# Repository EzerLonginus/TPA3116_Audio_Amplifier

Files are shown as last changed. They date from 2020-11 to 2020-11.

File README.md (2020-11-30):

# TPA3116_Audio_Amplifier
TPA3116 Stereo and Sub-Woofer Audio Amplifier.  D-Class 50W Stereo Amplifier.  The schematic and layout are pretty much similar to the one layout in the datasheet.  Nothing too fancy, however the Subwoofer does have a summed Left and Right channel via two 470 ohm resistors `R78 R79`. The input is assumed to be a line level stereo input through a 3.5mm jack.  However, there are some through hole pins should a different connector or input be desired.  The banana plug holes on the all the speaker ouputs are for potential convenience for swapping out speakers.  Not strictly necessary, one could solder speaker cable to those through holes, or just juse the screw terminals.  The banana plugs for the power input are there for similar reasons.  

## Schematic
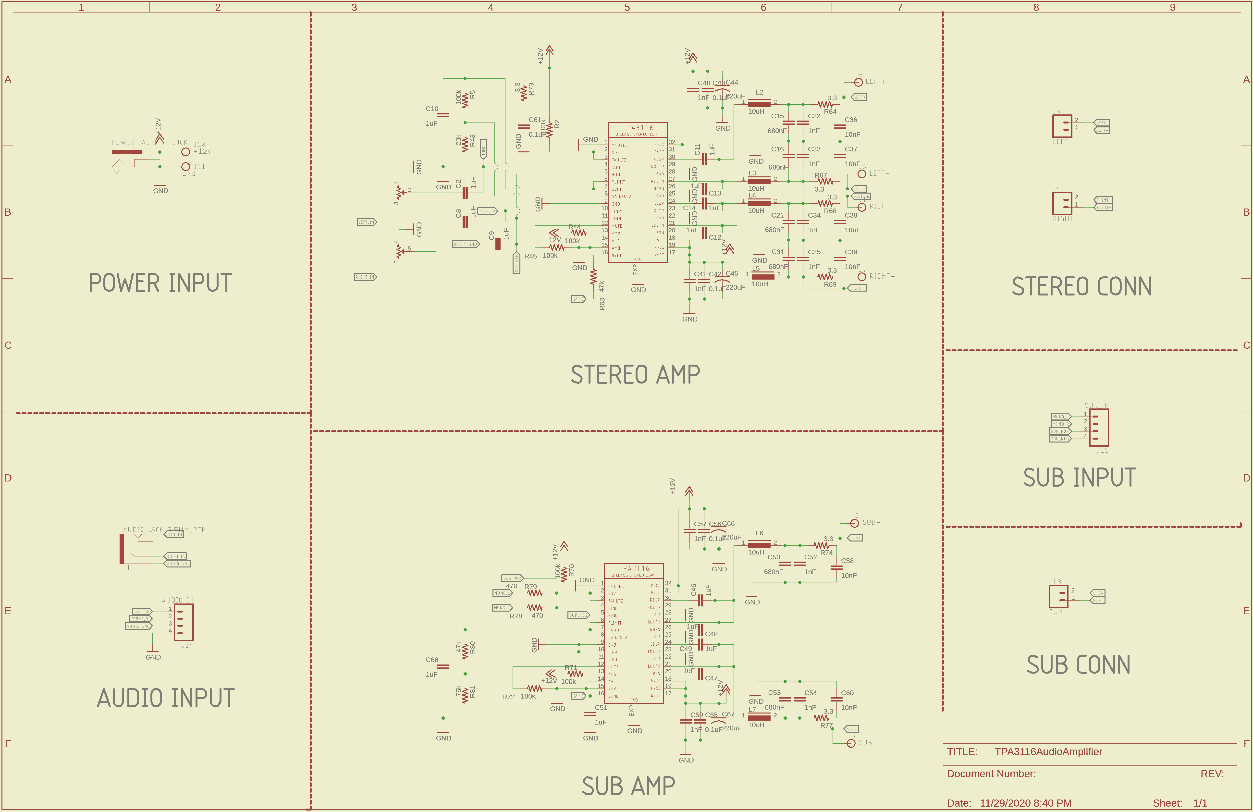
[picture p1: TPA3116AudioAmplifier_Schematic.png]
Schematic


## Layout
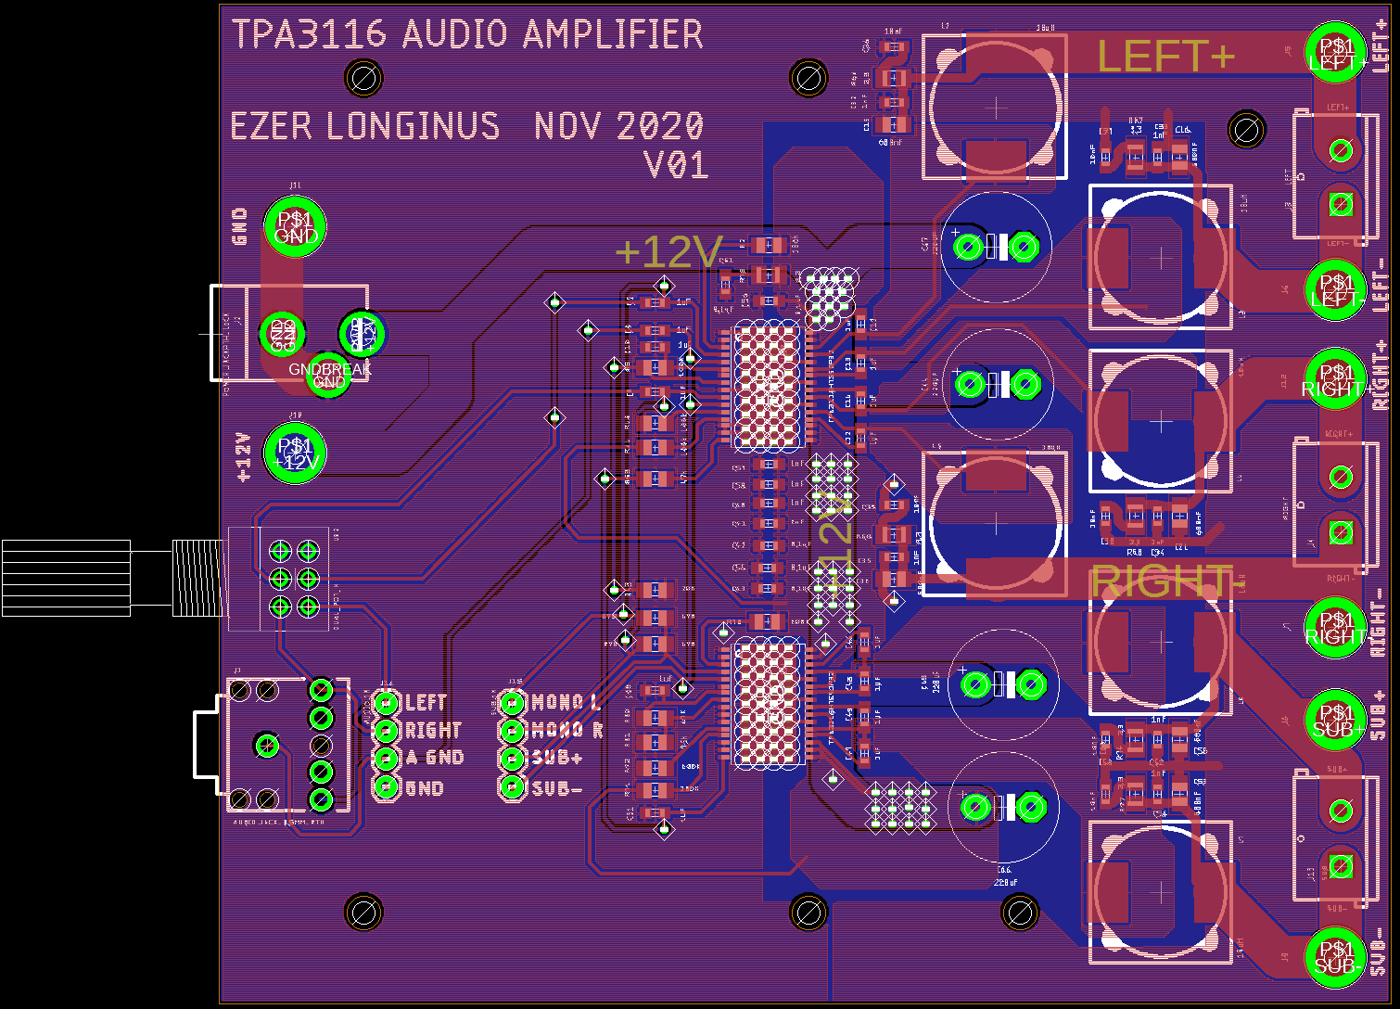
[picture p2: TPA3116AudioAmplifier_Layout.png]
Layout


## BOM Link
1. [OCTOPART BOM](https://octopart.com/bom-tool/Kn64f8nE)

## Datasheets and External Links
1. [TPA3116](https://www.ti.com/lit/ds/symlink/tpa3116d2.pdf)

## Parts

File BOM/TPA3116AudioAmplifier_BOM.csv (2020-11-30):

Qty | Line Item | Manufacturer | MPN | Octopart URL | Schematic Reference | Internal Part Number | Description | Total Qty (@ Batch Size: 1) | SKU | SKU | SKU | SKU | Packaging | Packaging | Packaging | Packaging | Unit Price (@ Batch Size: 1) | Unit Price (@ Batch Size: 1) | Unit Price (@ Batch Size: 1) | Unit Price (@ Batch Size: 1) | In Stock | In Stock | In Stock | In Stock | MOQ | MOQ | MOQ | MOQ | URL | URL | URL | URL | Distributor [Lowest Price (Overall)] | SKU [Lowest Price (Overall)] | Packaging [Lowest Price (Overall)] | Unit Price (@ Batch Size: 1) [Lowest Price (Overall)] | Line Total [Lowest Price (Overall)] | Batch Total [Lowest Price (Overall)] | In Stock [Lowest Price (Overall)] | MOQ [Lowest Price (Overall)] | URL [Lowest Price (Overall)] | Notes
 |  |  |  |  |  |  |  |  | Digi-Key | Future Electronics | Mouser | RS Components | Digi-Key | Future Electronics | Mouser | RS Components | Digi-Key | Future Electronics | Mouser | RS Components | Digi-Key | Future Electronics | Mouser | RS Components | Digi-Key | Future Electronics | Mouser | RS Components | Digi-Key | Future Electronics | Mouser | RS Components
14 | UMK107BJ105KA-T | Taiyo Yuden | UMK107BJ105KA-T | https://octopart.com/umk107bj105ka-t-taiyo+yuden-12090744 | C2 C8 C9 C10 C11 C12 C13 C14 C46 C47 C48 C49 C51 C68 |  | CAP CER 1UF 50V X5R 0603 | 14 | 587-2400-1-ND | 5104254 |  | 1034112 | Cut Tape | Cut Tape |  |  | 0.124 | 0.176 |  |  | 2043939 | 119583 |  | 4400 | 1 | 1 |  | 100 | https://octopart.com/click/track?ai=8237&sig=0510af6&sid=459&ppid=12090744&vpid=34090480&ct=offers | https://octopart.com/click/track?ai=8237&sig=0335285&sid=2454&ppid=12090744&vpid=495873363&ct=offers |  | https://octopart.com/click/track?ai=8237&sig=0923c07&sid=10022&ppid=12090744&vpid=575871653&ct=offers | Freelance Electronics | UMK107BJ105KA-T |  | 0.0096 | 0.1344 | 0.1344 | 1484 | 1 | https://octopart.com/click/track?ai=8237&sig=025401f&sid=13062&ppid=12090744&vpid=592344908&ct=offers
6 | CL21B684KBFVPNE | Samsung | CL21B684KBFVPNE | https://octopart.com/cl21b684kbfvpne-samsung-76986280 | C15 C16 C21 C31 C50 C53 |  | CAP CER 0.68UF 50V X7R 0805 | 6 | 1276-7009-1-ND |  |  |  | Cut Tape |  |  |  | 0.19 |  |  |  | 45805 |  |  |  | 1 |  |  |  | https://octopart.com/click/track?c=1&ai=8237&sig=0b574c6&sid=459&ppid=76986280&vpid=426278556&ct=offers |  |  |  | Digi-Key | 1276-7009-1-ND | Cut Tape | 0.19 | 1.1400000000000001 | 1.1400000000000001 | 45805 | 1 | https://octopart.com/click/track?c=1&ai=8237&sig=0b574c6&sid=459&ppid=76986280&vpid=426278556&ct=offers
9 | CL10B102KB8NNNC | Samsung | CL10B102KB8NNNC | https://octopart.com/cl10b102kb8nnnc-samsung-9301522 | C32 C33 C34 C40 C41 C52 C54 C57 C59 |  | CAP CER 1000PF 50V X7R 0603 | 9 | 1276-1018-1-ND | 3573581 |  | 7665272 | Cut Tape | Cut Tape |  |  | 0.1 | 0.0091 |  |  | 572722 | 1136132 |  | 136000 | 1 | 1 |  | 4000 | https://octopart.com/click/track?ai=8237&sig=0138e6a&sid=459&ppid=9301522&vpid=72523792&ct=offers | https://octopart.com/click/track?ai=8237&sig=0fb88a5&sid=2454&ppid=9301522&vpid=657046416&ct=offers |  | https://octopart.com/click/track?ai=8237&sig=094158c&sid=10022&ppid=9301522&vpid=575772081&ct=offers | Future Electronics | 3573581 | Cut Tape | 0.0091 | 0.0819 | 0.0819 | 1136132 | 1 | https://octopart.com/click/track?ai=8237&sig=0fb88a5&sid=2454&ppid=9301522&vpid=657046416&ct=offers
6 | CL10B103KB8NNNC | Samsung | CL10B103KB8NNNC | https://octopart.com/cl10b103kb8nnnc-samsung-9299374 | C36 C37 C38 C39 C58 C60 |  | CAP CER 10000PF 50V X7R 0603 | 6 | 1276-1009-1-ND | 7103639 |  | 7665373 | Cut Tape | Cut Tape |  |  | 0.1 | 0.0079 |  |  | 2658585 | 1432961 |  | 6232000 | 1 | 1 |  | 4000 | https://octopart.com/click/track?ai=8237&sig=08f0957&sid=459&ppid=9299374&vpid=72523832&ct=offers | https://octopart.com/click/track?ai=8237&sig=08b147c&sid=2454&ppid=9299374&vpid=495872440&ct=offers |  | https://octopart.com/click/track?ai=8237&sig=09d8818&sid=10022&ppid=9299374&vpid=575772086&ct=offers | Newark | 82AC9315 | Cut Tape | 0.005 | 0.03 | 0.03 | 44883 | 1 | https://octopart.com/click/track?ai=8237&sig=00bc199&sid=2402&ppid=9299374&vpid=511545493&ct=offers
5 | CL10B104KB8NNNL | Samsung | CL10B104KB8NNNL | https://octopart.com/cl10b104kb8nnnl-samsung-21395620 | C42 C43 C55 C56 C61 |  | CAP CER 0.1UF 50V X7R 0603 | 5 | 1276-CL10B104KB8NNNLCT-ND | 3113240 | 187-CL10B104KB8NNNL |  | Cut Tape | Cut Tape | Tape & Reel |  | 0.1 | 0.098 |  |  | 5868552 | 570651 | 438200 |  | 1 | 1 | 15000 |  | https://octopart.com/click/track?ai=8237&sig=0e9765d&sid=459&ppid=21395620&vpid=578720948&ct=offers | https://octopart.com/click/track?ai=8237&sig=0f2016f&sid=2454&ppid=21395620&vpid=657046465&ct=offers | https://octopart.com/click/track?ai=8237&sig=00540b2&sid=2401&ppid=21395620&vpid=659501131&ct=offers |  | Arrow.cn | CL10B104KB8NNNL#SAMSUNGE |  | 0.028 | 0.14 | 0.14 | 10928 | 1 | https://octopart.com/click/track?ai=8237&sig=07a3a2f&sid=28928&ppid=21395620&vpid=642249454&ct=offers
4 | ESE227M050AH9EA | KEMET | ESE227M050AH9EA | https://octopart.com/ese227m050ah9ea-kemet-92837938 | C44 C45 C66 C67 |  | CAP ALUM 220UF 20% 50V THRUHOLE | 4 | 399-18266-1-ND |  |  |  | Cut Tape |  |  |  | 0.37 |  |  |  | 101 |  |  |  | 1 |  |  |  | https://octopart.com/click/track?c=1&ai=8237&sig=0bcd6f5&sid=459&ppid=92837938&vpid=484652430&ct=offers |  |  |  | Digi-Key | 399-18266-1-ND | Cut Tape | 0.37 | 1.48 | 1.48 | 101 | 1 | https://octopart.com/click/track?c=1&ai=8237&sig=0bcd6f5&sid=459&ppid=92837938&vpid=484652430&ct=offers
1 | SJ1-3555NG | CUI Devices | SJ1-3555NG | https://octopart.com/sj1-3555ng-cui+devices-106234295 | J1 |  | CONN JACK STEREO 3.5MM R/A | 1 | CP1-3555NG-ND | 6034303 |  |  | Bag | Box |  |  | 0.9 | 0.55 |  |  | 14884 | 12500 |  |  | 1 | 1 |  |  | https://octopart.com/click/track?ai=8237&sig=028bb4d&sid=459&ppid=106234295&vpid=612420483&ct=offers | https://octopart.com/click/track?ai=8237&sig=02bc3c9&sid=2454&ppid=106234295&vpid=656992232&ct=offers |  |  | Future Electronics | 6034303 | Box | 0.55 | 0.55 | 0.55 | 12500 | 1 | https://octopart.com/click/track?ai=8237&sig=02bc3c9&sid=2454&ppid=106234295&vpid=656992232&ct=offers
3 | 282836-2 | TE Connectivity | 282836-2 | https://octopart.com/282836-2-te+connectivity-39396934 | J3 J4 J13 |  | TERM BLK 2POS SIDE ENTRY 5MM PCB | 3 | A98076-ND | 4188728 |  | 3617667 | Box | Bag |  |  | 0.71 | 0.295 |  |  | 34141 | 8601 |  | 5005 | 1 | 1 |  | 5 | https://octopart.com/click/track?ai=8237&sig=03766e2&sid=459&ppid=39396934&vpid=198635742&ct=offers | https://octopart.com/click/track?ai=8237&sig=0dfe638&sid=2454&ppid=39396934&vpid=416937788&ct=offers |  | https://octopart.com/click/track?ai=8237&sig=01d4f22&sid=10022&ppid=39396934&vpid=575813511&ct=offers | Sager Electronics | 282836-2 |  | 0.2355 | 0.7064999999999999 | 0.7064999999999999 | 0 | 1 | https://octopart.com/click/track?c=1&ai=8237&sig=0304f12&sid=15568&ppid=39396934&vpid=115559715&ct=offers
8 | 476-4 | Keystone | 476-4 | https://octopart.com/476-4-keystone-225161 | J5 J6 J7 J8 J9 J10 J11 J12 |  | CONN BANANA JACK MINIATURE SLDR | 8 | 36-476-4-ND |  | 534-476-4 |  | Bulk |  | Bulk |  | 0.69 |  | 0.66 |  | 3510 |  | 289 |  | 1 |  | 1 |  | https://octopart.com/click/track?ai=8237&sig=076c679&sid=459&ppid=225161&vpid=212427319&ct=offers |  | https://octopart.com/click/track?ai=8237&sig=075d1a8&sid=2401&ppid=225161&vpid=37932047&ct=offers |  | Carlton-Bates | 78382499741 |  | 0.64 | 5.12 | 5.12 | 0 | 1 | https://octopart.com/click/track?c=1&ai=8237&sig=0dcadd2&sid=18369&ppid=225161&vpid=521658433&ct=offers
6 | SRR1208-100ML | Bourns | SRR1208-100ML | https://octopart.com/srr1208-100ml-bourns-148118 | L2 L3 L4 L5 L6 L7 |  | FIXED IND 10UH 5A 21 MOHM SMD | 6 | SRR1208-100MLCT-ND |  |  | 6934530 | Cut Tape |  |  |  | 0.98 |  |  | 0.845 | 11953 |  |  | 221 | 1 |  |  | 1 | https://octopart.com/click/track?ai=8237&sig=01733f2&sid=459&ppid=148118&vpid=34264358&ct=offers |  |  | https://octopart.com/click/track?ai=8237&sig=0c0d7fa&sid=10022&ppid=148118&vpid=575456154&ct=offers | Avnet | 83R8946 |  | 0.47 | 2.82 | 2.82 | 800 | 1 | https://octopart.com/click/track?ai=8237&sig=0ac58d9&sid=5822&ppid=148118&vpid=503036623&ct=offers
7 | RR1220P-104-D | Susumu | RR1220P-104-D | https://octopart.com/rr1220p-104-d-susumu-981652 | R2 R5 R44 R46 R70 R71 R72 |  | RES SMD 100K OHM 0.5% 1/10W 0805 | 7 | RR12P100KDCT-ND | 2474021 |  | 3915719 | Cut Tape | Cut Tape |  |  | 0.1 | 0.108 |  |  | 368982 | 70469 |  | 500 | 1 | 1 |  | 100 | https://octopart.com/click/track?ai=8237&sig=0299d6a&sid=459&ppid=981652&vpid=1542037&ct=offers | https://octopart.com/click/track?ai=8237&sig=022a240&sid=2454&ppid=981652&vpid=19675409&ct=offers |  | https://octopart.com/click/track?ai=8237&sig=0dd98c3&sid=10022&ppid=981652&vpid=576840281&ct=offers | Newark | 28K0934 | Cut Tape | 0.013 | 0.091 | 0.091 | 26418 | 1 | https://octopart.com/click/track?ai=8237&sig=0f3df14&sid=2402&ppid=981652&vpid=2942947&ct=offers
1 | ERA-6AEB203V | Panasonic | ERA6AEB203V | https://octopart.com/era6aeb203v-panasonic-55396948 | R43 |  | RES 20K OHM 0.1% 1/8W 0805 | 1 | P20KDACT-ND | 5098752 |  |  | Cut Tape | Cut Tape |  |  | 0.31 | 0.355 |  |  | 50759 | 25110 |  |  | 1 | 1 |  |  | https://octopart.com/click/track?ai=8237&sig=0c06205&sid=459&ppid=55396948&vpid=118268838&ct=offers | https://octopart.com/click/track?ai=8237&sig=03b0c2d&sid=2454&ppid=55396948&vpid=477169642&ct=offers |  |  | Avnet | 01X1369 |  | 0.044 | 0.044 | 0.044 | 35000 | 1 | https://octopart.com/click/track?ai=8237&sig=03a8e8a&sid=5822&ppid=55396948&vpid=503227276&ct=offers
2 | RC0805FR-0747KL | Yageo | RC0805FR-0747KL | https://octopart.com/rc0805fr-0747kl-yageo-41205014 | R63 R80 |  | RES SMD 47K OHM 1% 1/8W 0805 | 2 | 311-47.0KCRCT-ND | 2963700 |  | 6182580 | Cut Tape | Cut Tape |  |  | 0.1 | 0.0041 |  |  | 903107 | 1316495 |  | 50000 | 1 | 1 |  | 5000 | https://octopart.com/click/track?ai=8237&sig=0fa6774&sid=459&ppid=41205014&vpid=114983320&ct=offers | https://octopart.com/click/track?ai=8237&sig=01c416f&sid=2454&ppid=41205014&vpid=416982216&ct=offers |  | https://octopart.com/click/track?ai=8237&sig=0af9f31&sid=10022&ppid=41205014&vpid=575956811&ct=offers | Future Electronics | 2963700 | Cut Tape | 0.0041 | 0.0082 | 0.0082 | 1316495 | 1 | https://octopart.com/click/track?ai=8237&sig=01c416f&sid=2454&ppid=41205014&vpid=416982216&ct=offers
7 | ERJ-6DQJ3R3V | Panasonic | ERJ-6DQJ3R3V | https://octopart.com/erj-6dqj3r3v-panasonic-73854714 | R64 R67 R68 R69 R73 R74 R77 |  | RES SMD 3.3 OHM 5% 1/2W 0805 | 7 | P19232CT-ND |  | 667-ERJ-6DQJ3R3V |  | Cut Tape |  | Tape & Reel |  | 0.22 |  | 0.24 |  | 5789 |  | 8945 |  | 1 |  | 1 |  | https://octopart.com/click/track?ai=8237&sig=003a468&sid=459&ppid=73854714&vpid=260674842&ct=offers |  | https://octopart.com/click/track?ai=8237&sig=089cafd&sid=2401&ppid=73854714&vpid=449222001&ct=offers |  | Arrow Electronics | ERJ-6DQJ3R3V | Cut Tape | 0.0356 | 0.2492 | 0.2492 | 3348 | 1 | https://octopart.com/click/track?ai=8237&sig=0399884&sid=1106&ppid=73854714&vpid=473401022&ct=offers
2 | CRGCQ0805F470R | TE Connectivity | CRGCQ0805F470R | https://octopart.com/crgcq0805f470r-te+connectivity-91018180 | R78 R79 |  | CRGCQ 0805 470R 1% | 2 | A129745CT-ND |  | 279-CRGCQ0805F470R |  | Cut Tape |  | Tape & Reel |  | 0.1 |  | 0.1 |  | 41548 |  | 15141 |  | 1 |  | 1 |  | https://octopart.com/click/track?ai=8237&sig=041f101&sid=459&ppid=91018180&vpid=475508772&ct=offers |  | https://octopart.com/click/track?ai=8237&sig=01408f3&sid=2401&ppid=91018180&vpid=478301030&ct=offers |  | TE Store | CRGCQ0805F470R |  | 0.02 | 0.04 | 0.04 | 41648 | 1 | https://octopart.com/click/track?ai=8237&sig=076bf19&sid=27910&ppid=91018180&vpid=610745516&ct=offers
1 | RR1220P-753-D | Susumu | RR1220P-753-D | https://octopart.com/rr1220p-753-d-susumu-1234488 | R81 |  | RES SMD 75K OHM 0.5% 1/10W 0805 | 1 | RR12P75.0KDCT-ND | 2661106 |  |  | Cut Tape | Tape & Reel |  |  | 0.1 |  |  |  | 23403 | 0 |  |  | 1 | 5000 |  |  | https://octopart.com/click/track?c=1&ai=8237&sig=06024cd&sid=459&ppid=1234488&vpid=1967962&ct=offers | https://octopart.com/click/track?c=1&ai=8237&sig=08d486b&sid=2454&ppid=1234488&vpid=110067476&ct=offers |  |  | Voyager Components | RR1220P-753-D-SUSUMU-N/A |  | 0.01 | 0.01 | 0.01 | 5000 | 1 | https://octopart.com/click/track?ai=8237&sig=0c48448&sid=2424&ppid=1234488&vpid=590647227&ct=offers
2 | TPA3116D2DAD | Texas Instruments | TPA3116D2DAD | https://octopart.com/tpa3116d2dad-texas+instruments-22616226 | U$1 U$3 |  | IC AMP CLASS D STER 50W 32HTSSOP | 2 | 296-30433-5-ND |  | 595-TPA3116D2DAD | 8124224 | Tube |  | Tube |  | 3.02 |  | 3.03 | 2.959 | 817 |  | 246 | 8 | 1 |  | 1 | 1 | https://octopart.com/click/track?ai=8237&sig=0bf575f&sid=459&ppid=22616226&vpid=50027165&ct=offers |  | https://octopart.com/click/track?ai=8237&sig=05714de&sid=2401&ppid=22616226&vpid=52838523&ct=offers | https://octopart.com/click/track?ai=8237&sig=0bec2c3&sid=10022&ppid=22616226&vpid=575885719&ct=offers | Rochester Electronics | TPA3116D2DAD |  | 1.7051 | 3.4102 | 3.4102 | 27 | 1 | https://octopart.com/click/track?ai=8237&sig=0c4b7e5&sid=5832&ppid=22616226&vpid=182249048&ct=offers
2 | 20188 | Watterott | 20188 | https://octopart.com/20188-watterott-106685580 |  |  | SILENTSTEPSTICK HEATSINK 9 X 9 X | 2 | 2100-20188-ND |  |  |  | Bulk |  |  |  | 0.93 |  |  |  | 983 |  |  |  | 1 |  |  |  | https://octopart.com/click/track?c=1&ai=8237&sig=0bf34c1&sid=459&ppid=106685580&vpid=597361357&ct=offers |  |  |  | Digi-Key | 2100-20188-ND | Bulk | 0.93 | 1.86 | 1.86 | 983 | 1 | https://octopart.com/click/track?c=1&ai=8237&sig=0bf34c1&sid=459&ppid=106685580&vpid=597361357&ct=offers
1 | PTD902-2020K-A103 | Bourns | PTD902-2020K-A103 | https://octopart.com/ptd902-2020k-a103-bourns-1765105 | U$2 |  | POT 10K OHM 1/40W CARBON LOG | 1 | PTD902-2020K-A103-ND |  | 652-PTD902-2020KA103 |  | Tray |  | Bulk |  | 2.01 |  | 2.01 |  | 124 |  | 137 |  | 1 |  | 1 |  | https://octopart.com/click/track?ai=8237&sig=08f9882&sid=459&ppid=1765105&vpid=62989488&ct=offers |  | https://octopart.com/click/track?ai=8237&sig=0988985&sid=2401&ppid=1765105&vpid=37760781&ct=offers |  | Digi-Key | PTD902-2020K-A103-ND | Tray | 2.01 | 2.01 | 2.01 | 124 | 1 | https://octopart.com/click/track?ai=8237&sig=08f9882&sid=459&ppid=1765105&vpid=62989488&ct=offers
1 | PJ-037AH | CUI Devices | PJ-037AH | https://octopart.com/pj-037ah-cui+devices-106234005 | J2 |  | CONN PWR JACK 2X5.5MM SOLDER | 1 | CP-037AH-ND | 2052490 |  |  | Bag | Box |  |  | 0.71 | 0.39 |  |  | 30642 | 21 |  |  | 1 | 1 |  |  | https://octopart.com/click/track?ai=8237&sig=0e85f88&sid=459&ppid=106234005&vpid=612419795&ct=offers | https://octopart.com/click/track?ai=8237&sig=00169c3&sid=2454&ppid=106234005&vpid=656992088&ct=offers |  |  | Ameya360 | PJ-037AH | Box | 0.3465 | 0.3465 | 0.3465 | 500 | 1 | https://octopart.com/click/track?ai=8237&sig=03a1b97&sid=27291&ppid=106234005&vpid=439819909&ct=offers

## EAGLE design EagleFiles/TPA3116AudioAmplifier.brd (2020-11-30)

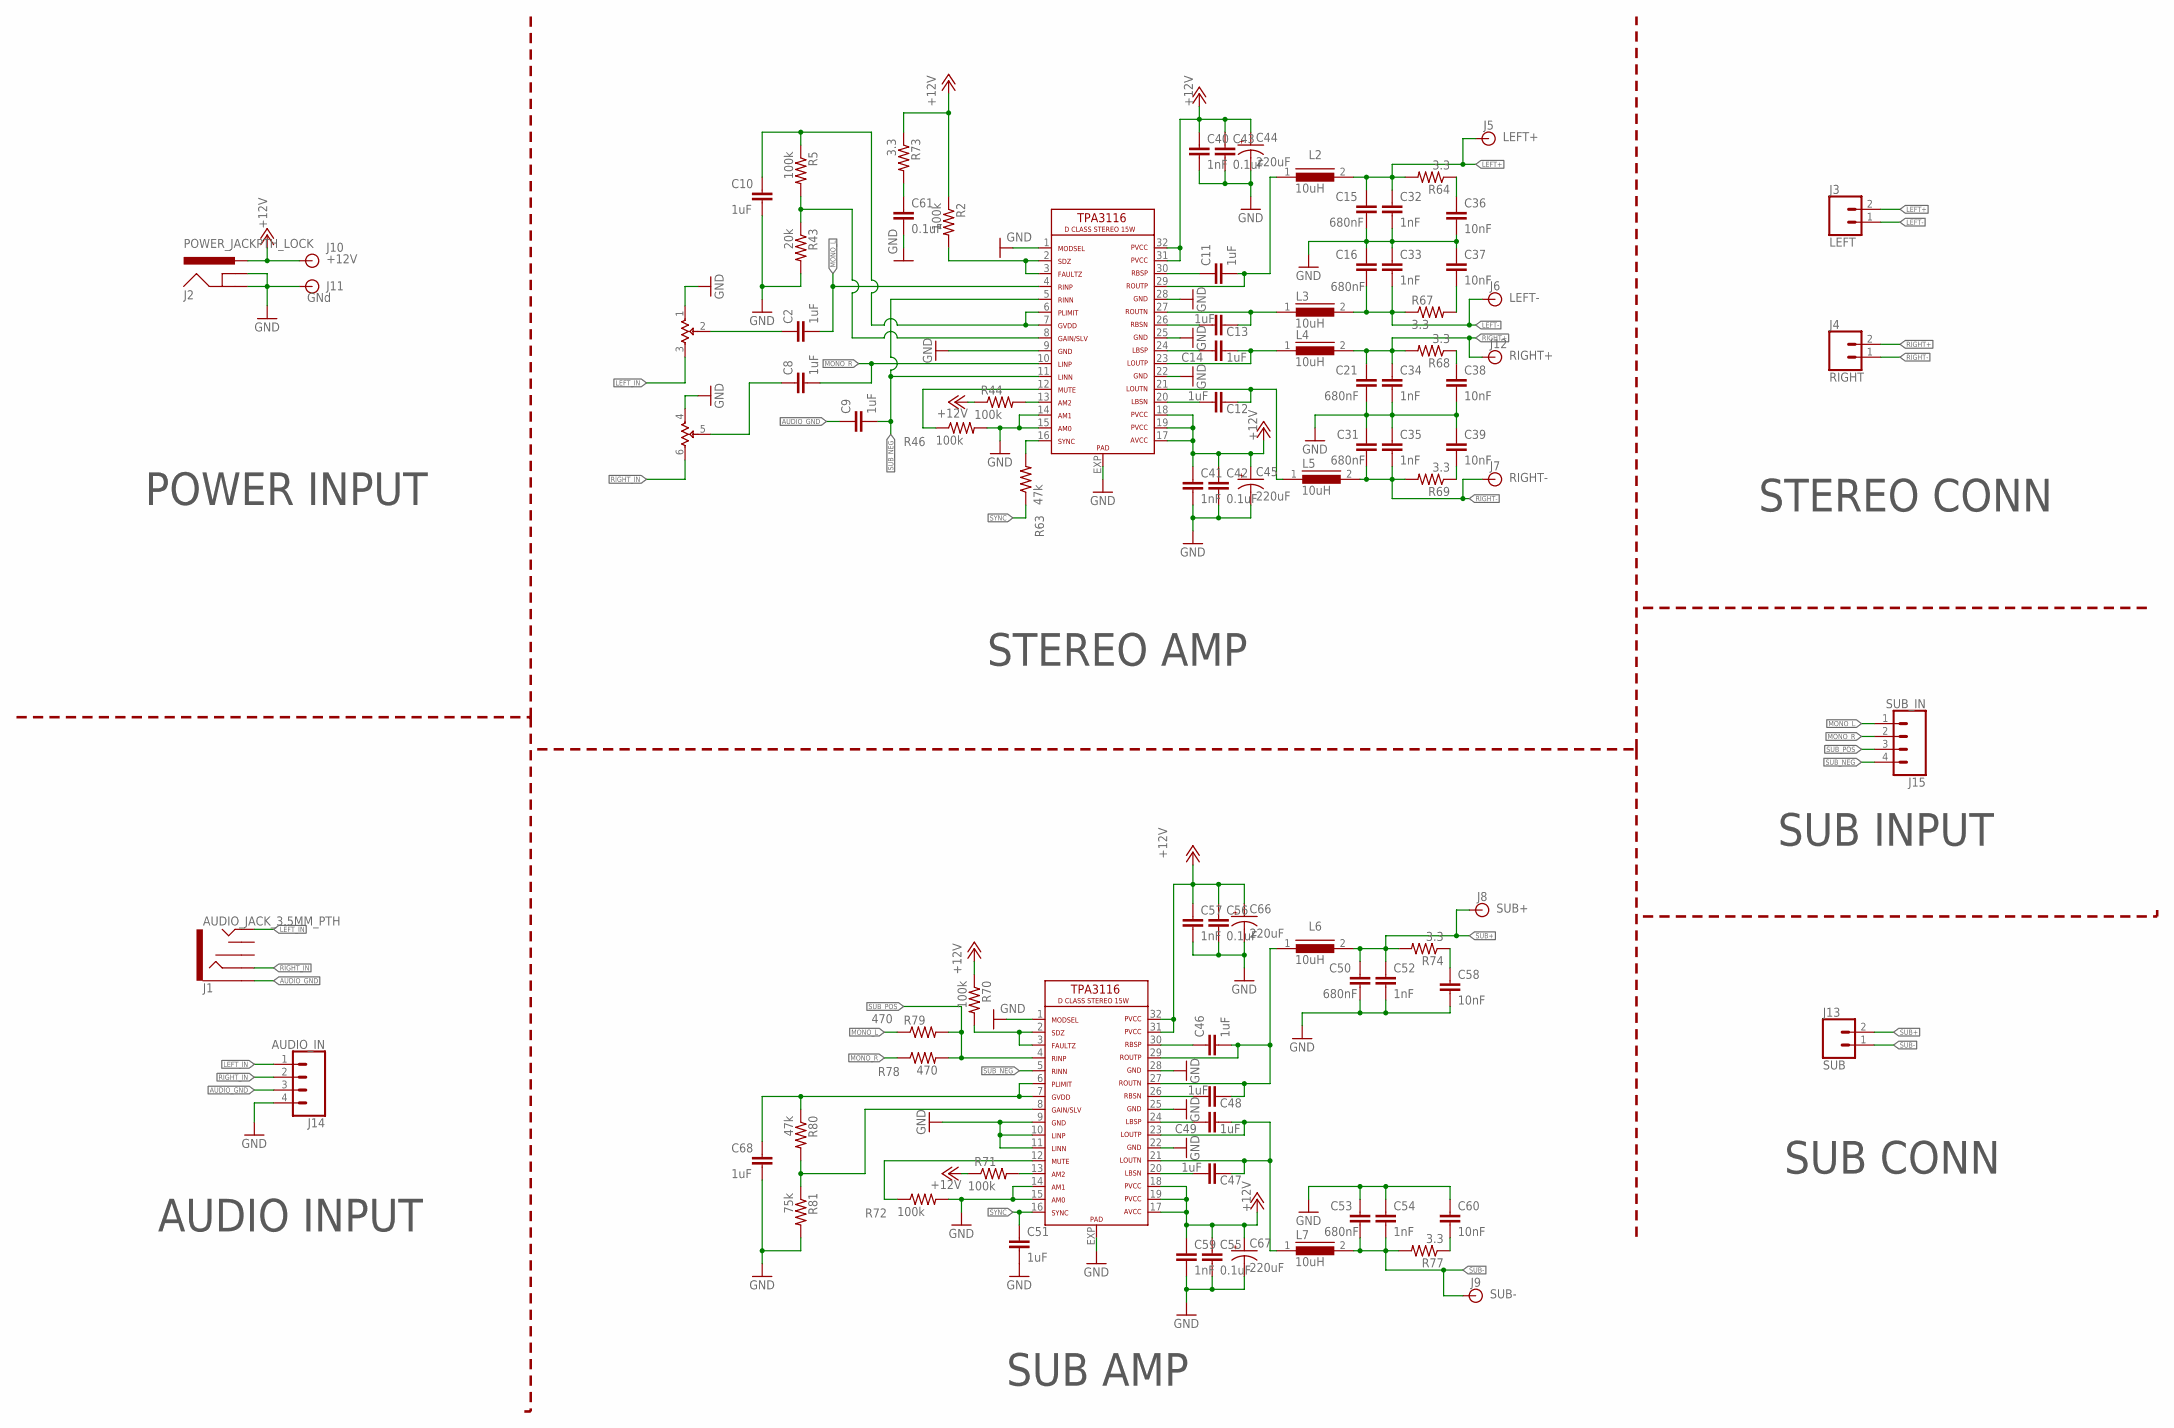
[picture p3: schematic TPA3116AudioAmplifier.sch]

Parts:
C2, C8, C9, C10, C11, C12, C13, C14, C46, C47, C48, C49, C51, C68: 1uF; C0603K
C15, C16, C21, C31, C50, C53: 680nF; C0805
C32, C33, C34, C35, C40, C41, C52, C54, C57, C59: 1nF; C0603K
C36, C37, C38, C39, C58, C60: 10nF; C0603K
C42, C43, C55, C56, C61: 0.1uF; C0603K
C44, C45, C66, C67: 220uF; E5-10,5
J1: AUDIO_JACK_3.5MM_PTH; AUDIO-JACK
J2: POWER_JACKPTH_LOCK; POWER_JACK_PTH_LOCK
J3: LEFT; SCREWTERMINAL-5MM-2
J4: RIGHT; SCREWTERMINAL-5MM-2
J5: LEFT+; BANANA_CONN
J6: LEFT-; BANANA_CONN
J7: RIGHT-; BANANA_CONN
J8: SUB+; BANANA_CONN
J9: SUB-; BANANA_CONN
J10: +12V; BANANA_CONN
J11: GNd; BANANA_CONN
J12: RIGHT+; BANANA_CONN
J13: SUB; SCREWTERMINAL-5MM-2
J14: AUDIO_IN; 1X04
J15: SUB_IN; 1X04
L2, L3, L4, L5, L6, L7: 10uH; DR125
R2, R5, R44, R46, R70, R71, R72: 100k; R0805
R43: 20k; R0805
R63, R80: 47k; R0805
R64, R67, R68, R69, R73, R74, R77: 3.3; M0805
R78, R79: 470; R0805
R81: 75k; R0805
U$1, U$3: TPA3116HTSSOP32; HTSSOP32DAP
U$2: DUAL_POT_H

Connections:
+12V: C40.1, C41.1, C42.1, C43.1, C44.+, C45.+, C55.1, C56.1, C57.1, C59.1, C66.+, C67.+, J2.PWR, J10.P$1, R2.1, R44.1, R70.1, R71.1, R73.1, U$1.17 (AVCC), U$1.18 (PVCC0), U$1.19 (PVCC1), U$1.31 (PVCC2), U$1.32 (PVCC3), U$3.17 (AVCC), U$3.18 (PVCC0), U$3.19 (PVCC1), U$3.31 (PVCC2), U$3.32 (PVCC3)
AUDIO_GND: C9.1, J1.SLEEVE, J14.3
GND: C10.2, C15.2, C16.1, C21.2, C31.1, C32.2, C33.1, C34.2, C35.1, C36.2, C37.1, C38.2, C39.1, C40.2, C41.2, C42.2, C43.2, C44.-, C45.-, C50.2, C51.2, C52.2, C53.1, C54.1, C55.2, C56.2, C57.2, C58.2, C59.2, C60.1, C61.2, C66.-, C67.-, C68.2, J2.GND, J2.GNDBREAK, J11.P$1, J14.4, R43.2, R46.2, R72.2, R81.2, U$1.1 (MODSEL), U$1.9 (GND0), U$1.10 (LINP), U$1.11 (LINN), U$1.14 (AM1), U$1.15 (AM0), U$1.22 (GND1), U$1.25 (GND2), U$1.28 (GND3), U$1.EXP, U$2.1, U$2.4, U$3.1 (MODSEL), U$3.9 (GND0), U$3.14 (AM1), U$3.15 (AM0), U$3.22 (GND1), U$3.25 (GND2), U$3.28 (GND3), U$3.EXP
LEFT+: C15.1, C32.1, J3.2, J5.P$1, L2.2, R64.2
LEFT-: C16.2, C33.2, J3.1, J6.P$1, L3.2, R67.1
LEFT_IN: J1.TIP, J14.1, U$2.3
LOUTN: C13.2, L3.1, U$3.27 (ROUTN)
LOUTP: C11.2, L2.1, U$3.29 (ROUTP)
MONO_L: C2.2, J15.1, R79.1, U$3.4 (RINP)
MONO_R: C8.2, J15.2, R78.1, U$3.10 (LINP)
unnamed: C8.1, U$2.5
unnamed: R70.2, U$1.2 (SDZ), U$1.3 (FAULTZ)
unnamed: C61.1, R73.2
unnamed: R2.2, U$3.2 (SDZ), U$3.3 (FAULTZ)
unnamed: R44.2, U$3.13 (AM2)
unnamed: R46.1, U$3.12 (MUTE)
unnamed: R5.2, R43.1, U$3.8 (GAIN/SLV)
unnamed: C2.1, U$2.2
unnamed: R80.2, R81.1, U$1.8 (GAIN/SLV)
unnamed: C10.1, R5.1, U$3.6 (PLIMIT), U$3.7 (GVDD)
unnamed: R63.2, U$3.16 (SYNC)
unnamed: C11.1, U$3.30 (RBSP)
unnamed: C12.1, U$3.20 (LBSN)
unnamed: C13.1, U$3.26 (RBSN)
unnamed: C14.1, U$3.24 (LBSP)
unnamed: C68.1, R80.1, U$1.6 (PLIMIT), U$1.7 (GVDD)
unnamed: R71.2, U$1.13 (AM2)
unnamed: C36.1, R64.1
unnamed: R72.1, U$1.12 (MUTE)
unnamed: C38.1, R68.1
unnamed: C37.2, R67.2
unnamed: C39.2, R69.1
unnamed: C46.1, U$1.30 (RBSP)
unnamed: C47.1, U$1.20 (LBSN)
unnamed: C48.1, U$1.26 (RBSN)
unnamed: C49.1, U$1.24 (LBSP)
unnamed: C58.1, R74.1
unnamed: C60.2, R77.1
RIGHT+: C21.1, C34.1, J4.2, J12.P$1, L4.2, R68.2
RIGHT-: C31.2, C35.2, J4.1, J7.P$1, L5.2, R69.2
RIGHT_IN: J1.RING, J14.2, U$2.6
ROUTN: C12.2, L5.1, U$3.21 (LOUTN)
ROUTP: C14.2, L4.1, U$3.23 (OUTPL)
SOUTN: C47.2, C49.2, L7.1, U$1.21 (LOUTN), U$1.23 (OUTPL)
SOUTP: C46.2, C48.2, L6.1, U$1.27 (ROUTN), U$1.29 (ROUTP)
SUB+: C50.1, C52.1, J8.P$1, J13.2, L6.2, R74.2
SUB-: C53.2, C54.2, J9.P$1, J13.1, L7.2, R77.2
SUB_NEG: C9.2, J15.4, U$1.5 (RINN), U$3.5 (RINN), U$3.11 (LINN)
SUB_POS: J15.3, R78.2, R79.2, U$1.4 (RINP)
SYNC: C51.1, R63.1, U$1.16 (SYNC)

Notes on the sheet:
SUB AMP
STEREO AMP
AUDIO INPUT
POWER INPUT
STEREO CONN
SUB INPUT
SUB CONN

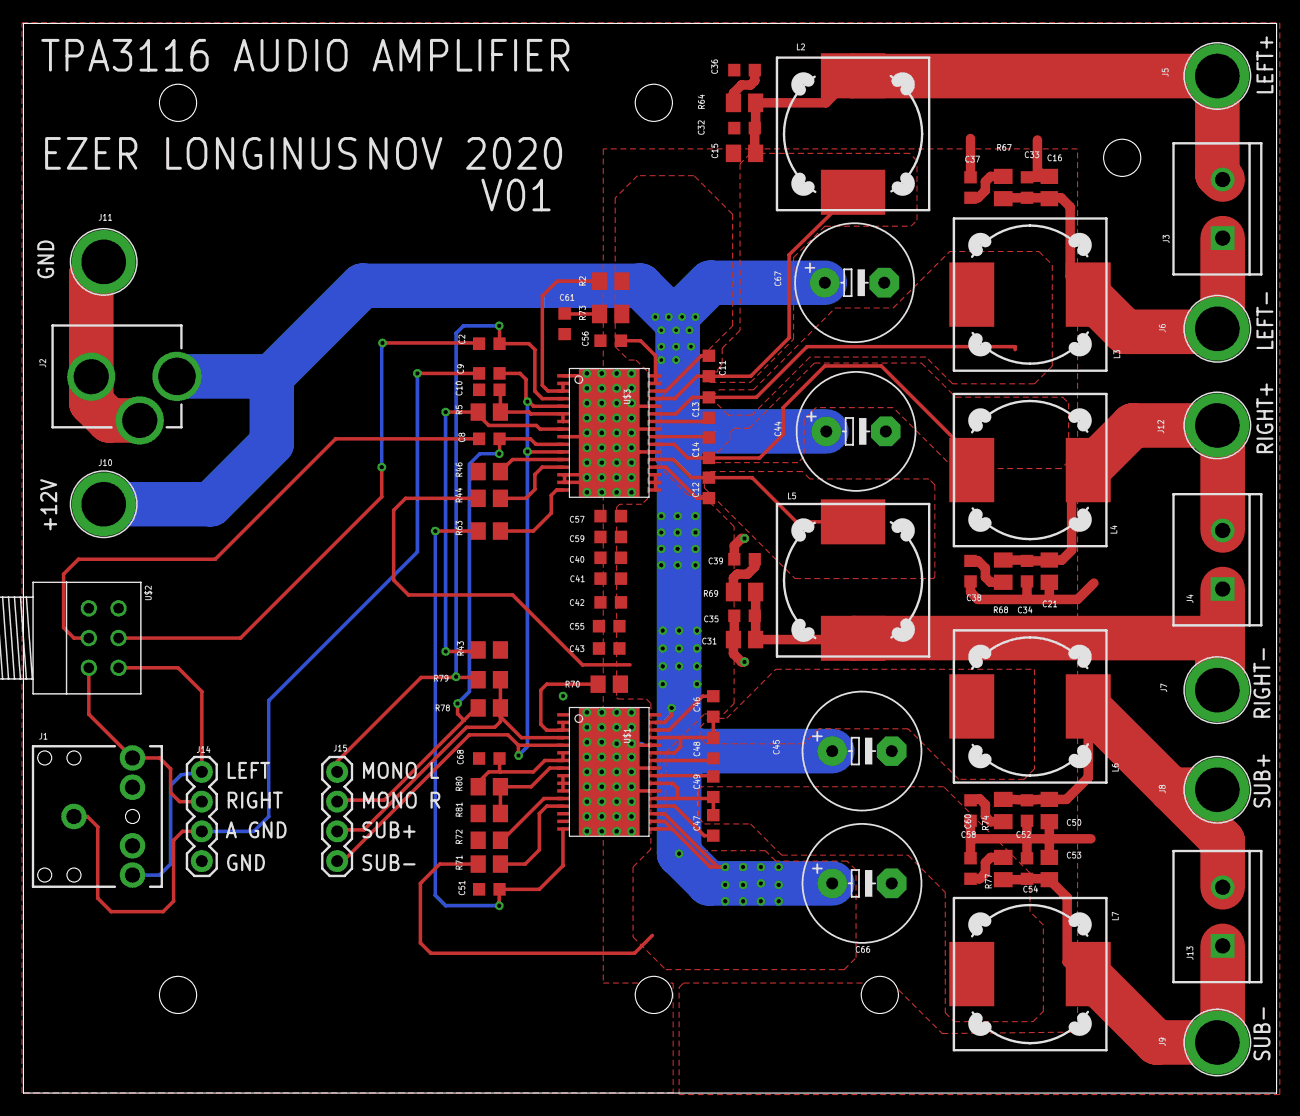
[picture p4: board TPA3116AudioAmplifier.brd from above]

Board: 2 copper layers, 107.0 x 91.4 mm, 89 parts (0 on the bottom side), 50 nets.

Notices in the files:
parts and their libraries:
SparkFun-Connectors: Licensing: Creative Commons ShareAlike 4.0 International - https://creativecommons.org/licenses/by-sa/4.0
